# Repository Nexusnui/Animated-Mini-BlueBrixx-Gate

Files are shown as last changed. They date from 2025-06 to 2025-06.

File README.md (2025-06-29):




# Animated-Mini-BlueBrixx-Gate (Instructions are currently WIP)
Animated Mini BlueBrixx Gate:
Gif of BlueBrixx Stargate

# About this project
With this project you can add a screen to your Mini Stargates from BlueBrixx, that display an animation of the event horizon.

# Partlist:
You can find all parts required for building the screen in the [Partlist](PARTLIST.md).

# Printing:
Advice/Settings for printing the shell can be found [here](3D_PRINTING.md)

# Software:
There are two ways top get the firmware onto the device the easiest beeing by [flashing the precompiled firmware](FLASH_FIRMWARE.md)(Only Windows) or [compiling it with Arduino](COMPILE_FIRMWARE.md).

# Assembly:
After printing and flashing the firmware you can follow this [assembly guide](ASSEMBLY.md) to put everything together.

# Sources:
- The main code uses a modified version of the [Gif viewer example(GIFDEC)](https://github.com/moononournation/Arduino_GFX/tree/master/examples/ImgViewer/ImgViewerAnimatedGIF_GIFDEC) from the [Arduino GFX library](https://github.com/moononournation/Arduino_GFX).
- The animtation was created based the one provided by David Gian-Cursion in [this blogpost](https://www.gian-cursio.net/2025/02/mr-stargate-puddle/). The current version has a blue tint and an alternative with the original colors will be provided later.
- The arduino sketch also includes some driver files from the demo provided on the [waveshare wiki](https://www.waveshare.com/wiki/ESP32-S3-LCD-1.85#Resources). I am not sure under what license they are provided, if you know any better or are from waveshare inform me and I will update this project accordingly.

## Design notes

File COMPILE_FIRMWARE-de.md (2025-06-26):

Hier ist die Anleitung zum Kompilieren der Firmware mit Arduino.

# 1. Arduino IDE 2.0 installieren

Installieren Sie zunächst die Arduino IDE für Ihr Betriebssystem (Windows/Mac/Linux). Sie können sie von [der offiziellen Arduino-Website](https://www.arduino.cc/en/software/), dem Windows Store, Flathub und anderen Quellen herunterladen.

# 2. Unterstützung für ESP32-Boards hinzufügen

1. Gehen Sie zu File->Preferences
2. Fügen Sie unter Settings die URL des Boardmanagers von Espressif Systems in das Feld „Additional board managers URLs“ ein.
	`https://espressif.github.io/arduino-esp32/package_esp32_index.json`
3. Speichern Sie Ihre Einstellungen, indem Sie auf „ok“ klicken.
4. Suchen Sie im Boardmanager nach esp32 und installieren Sie "esp32 by Espressif Systems" (>= 3.0.2).
5. Warten Sie, bis die Installation abgeschlossen ist.

Das Waveshare Wiki bietet die gleiche Anleitung auf English mit Bildern hier:  
[https://www.waveshare.com/wiki/Arduino_Board_Managers_Tutorial]

# 3. Arduino GFX installieren

1. Öffnen Sie den Bibliotheksmanager.
2. Suchen Sie nach "GFX Library for Arduino" (von "Moon On Our Nation").
3. Installiere sie diese (Version 1.6.0).

# 4. Den Arduino-Sketch herunterladen und öffnen

Folge diesen Schritten:
1. [Downloade die aktuell Quellcode Zip Datei](https://github.com/Nexusnui/Animated-Mini-BlueBrixx-Gate/releases/latest/download/Animated-Mini-BlueBrixx-Gate.zip)
2. Entpacken Sie den Inhalt der ZIP-Datei.
3. Gehen Sie zu "Animated-Mini-BlueBrixx-Gate-main/Code/animated-gate".
4. Öffnen Sie "animated-gate.ino" mit der Arduino IDE (ein Doppelklick sollte genügen).

# 5. Bereiten Sie die SD-Karte vor

1. Formatieren Sie Ihre SD-Karte mit „Fat32“ (je nach Betriebssystem benötigen Sie eventuell zusätzliche Software)
2. Verschieben Sie die Datei „PuddleLoop.gif“ aus dem Datenordner (innerhalb des Sketch-Ordners) auf die SD-Karte
3. Stecken Sie die Karte in das Display.

# 6. Stellen Sie die richtigen Projektparameter ein

1. Verbinden Sie das Display mit Ihrem PC über ein USB-C-Kabel
2. In Arduino IDE gehen Sie zu Tool->Board->esp32 und wählen Sie "ESP32S3 Dev Module"
3. Nehmen sie unter Tools die folgenden Einstellungen vor:
   - 'Events Run On: "Core 0"'
   - 'Flash Mode: "QIO 120MHz"'
   - 'Flash Size: "16MB (128Mb)"'
   - 'Arduino Runs On: "Core 1"'
   - 'USB Firmware MSC On Boot: "Disabled"'
   - 'Partition Scheme: "16M Flash (3MB APP/9.9MB FATFS)"'
   - 'PSRAM: "OPI PSRAM"'
   
Das Waveshare Wiki hat in Bild für die Einstellungen unter Tools (es zeigt aber ein anderes Partitionsschema):
[https://www.waveshare.com/wiki/ESP32-S3-LCD-1.85#Arduino_project_parameter_setting]

# 7. Hochladen des Sketches

1. Klicken Sie auf die Schaltfläche Upload.
2. Warten Sie, bis die Skizze kompiliert und hochgeladen ist.
3. Sie sollten nun die PuddleLoop-Animation auf dem Bildschirm sehen.

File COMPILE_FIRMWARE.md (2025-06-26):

These are the instructions for compiling the firmware with Arduino.

# 1. Install Arduino IDE 2.0

First install Arduino IDE for your operating system(Windows/Mac/Linux). You can download it from [the official Arduino website](https://www.arduino.cc/en/software/), the Windows Store, Flathub and other sources.

# 2. Add support for ESP32 boards

1. Go to File->Preferences
2. Under settings paste Espressif Systems board manager url into the "Additional board managers URLs" field.
	`https://espressif.github.io/arduino-esp32/package_esp32_index.json`
3. Save your settings by clicking 'ok'
4. In the board manager search for esp32 and inatall 'esp32 by Espressif Systems' (>= 3.0.2)
5. Wait for the installation to finish

The Waveshare Wiki provides the same guide with images here:  
[https://www.waveshare.com/wiki/Arduino_Board_Managers_Tutorial]

# 3. Install Arduino GFX

1. Open the library manager
2. Search for 'GFX Library for Arduino' (by 'Moon On Our Nation')
3. Install it (version 1.6.0)

# 4. Get the Arduino Sketch and open it

Follow these steps:  
1. [Download the latest released source code zip file](https://github.com/Nexusnui/Animated-Mini-BlueBrixx-Gate/releases/latest/download/Animated-Mini-BlueBrixx-Gate.zip)
2. Extract the content of the ZIP File
3. Go to 'Animated-Mini-BlueBrixx-Gate-main/Code/animated-gate'
4. Open 'animated-gate.ino' with Arduino IDE (just double clicking should work)

# 5. Prepare the SD Card

1. Format your sd card to "Fat32"(depending on your operating system you may require additional software)
2. Move the file "PuddleLoop.gif" from the data folder(inside the Sketch folder) to the sd Card
3. Insert the card into the display

# 6. Set the correct project parameters

1. Connect the display with your pc through a usb-c cable
2. In Arduino IDE go to Tool->Board->esp32 and select "ESP32S3 Dev Module"
3. Under tools apply the following settings:
   - 'Events Run On: "Core 0"'
   - 'Flash Mode: "QIO 120MHz"'
   - 'Flash Size: "16MB (128Mb)"'
   - 'Arduino Runs On: "Core 1"'
   - 'USB Firmware MSC On Boot: "Disabled"'
   - 'Partition Scheme: "16M Flash (3MB APP/9.9MB FATFS)"'
   - 'PSRAM: "OPI PSRAM"'
   
The Waveshare Wiki has in Image for the settings under tools(it shows a different partition scheme):
[https://www.waveshare.com/wiki/ESP32-S3-LCD-1.85#Arduino_project_parameter_setting]

# 7. Upload the Sketch

1. Hit the upload button
2. Wait for the Sketch to compile and Upload
3. You should now see the PuddleLoop animation on the screen

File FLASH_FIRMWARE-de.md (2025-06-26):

Dies sind die Anweisungen zum Flashen der bereits kompilierten Firmware. (Die kompilierte Firmware ist noch nicht verfügbar)

# 1. Bereiten Sie die SD-Karte vor
1. Formatieren Sie Ihre SD-Karte mit „Fat32“ (je nach Betriebssystem benötigen Sie eventuell zusätzliche Software)
2. Verschieben Sie die Datei „PuddleLoop.gif“ aus dem Datenordner (innerhalb des Sketch-Ordners) auf die SD-Karte
3. Stecken Sie die Karte in das Display.

# 2. Flashen Sie die Firmware
1. [Lade Sie die aktuelle Firmware herunter](https://github.com/Nexusnui/Animated-Mini-BlueBrixx-Gate/releases/latest/download/Animated-Mini-BlueBrixx-Gate.bin)
2. Befolgen Sie die Anweisungen im [Waveshare Wiki](https://www.waveshare.com/wiki/Flash_Firmware_Flashing_and_Erasing), aber wählen Sie die Firmware, die Sie zuvor heruntergeladen haben.

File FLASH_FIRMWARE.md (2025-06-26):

These are the instructions for flashing the already compiled firmware.

# 1. Prepare the SD Card
1. Format your sd card to "Fat32"(depending on your operating system you may require additional software)
2. Move the file "PuddleLoop.gif" from the data folder(inside the Sketch folder) to the sd Card
3. Insert the card into the display

# 2. Flash the firmware
1. [Download the latest released firmaware](https://github.com/Nexusnui/Animated-Mini-BlueBrixx-Gate/releases/latest/download/Animated-Mini-BlueBrixx-Gate.bin)
2. Follow the instructions from the [Waveshare Wiki](https://www.waveshare.com/wiki/Flash_Firmware_Flashing_and_Erasing), but select the firmware you downloaded previously.

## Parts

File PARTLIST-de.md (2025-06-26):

Dies ist die Teileliste für dieses Projekt

| Teil | Anzahl | Anmerkungen |
| :---: | -----: | :--- |
| Waveshare-ESP32-S3-LCD-1.85 | 1x | Die Version ohne Touch wird benötigt, wegen dem kleineren Rahmen hat |
| M2-Schrauben | 3x | Getestet mit einer Länge von 4 mm, etwas länger sollte auch funktionieren  |
| Bedruckte Mini Stargate Fliesen | 4x | Aus einem BlueBrixx-Set, das sie enthält |
| Tile, Round 1 x 1 with Bar and Pin Holder(20482) | 2x | Kann bei Händlern für Einzelsteine gekauft werden |
| Spule PLA (wenn man es selbst druckt) | ca.11g | Das Filament "Schimmernde Nacht" von Recycling Fabrik funktioniert gut |
| USB-C Kabel auf C/A (mit Datentransfer) | 1x | Kann ein rechtwinkliges sein oder man verwendet einen zusätzlichen Adapter |

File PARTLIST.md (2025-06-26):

This the partlist for this project

| Part | Count  | Notes |
| :---: | -----: | :--- |
| Waveshare-ESP32-S3-LCD-1.85 | 1x | The version without touch is required since it has a smaller bezel |
| M2 Screws | 3x | Tested with a length of 4mm slightly longer should work too |
| Tiles from Mini Stargate | 4x | Can be sourced from an BlueBrixx set that includes them. |
| Tile, Round 1 x 1 with Bar and Pin Holder(20482) | 2x | Can be sourced from shops that sell bricks |
| Spool of PLA (if you print it yourself) | ca.11g | The Filament "Schimmernde Nacht" by Recycling Fabrik works well |
| USB-C Cablet to C/A(with data transfer) | 1x | Can be a right angled one or use an additional adapter |

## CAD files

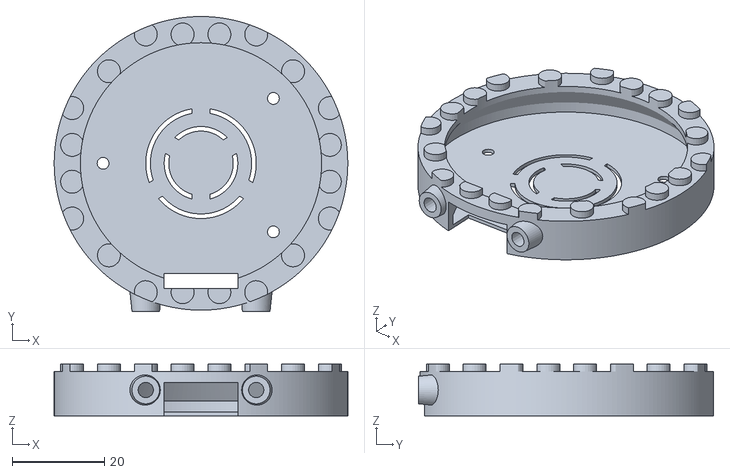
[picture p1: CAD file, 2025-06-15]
3D_Models/Screen_Shell.stl
63.8 x 64.1 x 11.2

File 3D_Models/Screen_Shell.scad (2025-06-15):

//Stud Tolerance added to the radius of a stud
st = 0.1; // .025

// include vent holes
include_vents = true;

/* [Curve Quality] */
// minimum angle for a fragment
$fa=2;
// minimum size of a fragment
$fs=0.6;

/* [Screen Offset Correction] */
//Correction of screen position on x axis.
screw_x_corr=0; // .025
//Correction of screen position on y axis.
screw_y_corr=0; // .025

module __Customizer_Limit__ () {}  // Hide following assignments from Customizer.

//Brick Variables names:
brick_b_u = 1.6;
brick_s_d = 3*brick_b_u;
brick_h = 6  * brick_b_u;
brick_p_h = 2 * brick_b_u;
brick_g_u = 5 * brick_b_u;

//Brick Variables as functions forexternal use:
function brick_base_unit(size=1) = brick_b_u*size;
function brick_stud_diameter(size=1) = brick_s_d*size;
function brick_heigth(size=1) = brick_h*size;
function brick_plate_heigth(size=1) = brick_p_h*size;
function brick_grid_unit(studs=1) = brick_g_u*studs;


gate_outer_d = 63.8;
screen_h = 8.7+0.1;
housing_h = brick_heigth();
housing_inner_d =52.4;
housing_bottom = housing_h-screen_h;

screw_dist = 23.93;
screw_x1 = -21.27;
screw_x2 = 15.73;
screw_y2 = 14.10;
screw_y3 = -14.90;
screw_shaft_d = 2+0.6;
echo(housing_inner_d);



module translate_brick(pos){
    b_g_x = pos[0] * brick_g_u;
    b_g_y = pos[1] * brick_g_u;
    if (is_num(pos[2])){
        b_g_z = pos[2] * brick_p_h;
        translate([ b_g_x, b_g_y, b_g_z])children();
    }else{
        translate([ b_g_x, b_g_y, 0])children();
    }
}

module stud(center=false,stud_tolerance=brick_st){
    if(center){
        cylinder(d=brick_s_d+stud_tolerance*2,h = brick_b_u);      
    }else{
        translate_brick([0.5,0.5,0])cylinder(d=brick_s_d+stud_tolerance*2,h = brick_b_u);
    }
}

module housing(){
difference(){
union(){
cylinder(d=gate_outer_d,h=housing_h);

translate([0,-0.2,0])translate_brick([1.5,-4,1.75])rotate([-90,0,0])cylinder(h=brick_heigth(),d2=brick_grid_unit(),d1=brick_stud_diameter(1.25));
translate([0,-0.2,0])translate_brick([-1.5,-4,1.75])rotate([-90,0,0])cylinder(h=brick_heigth(),d2=brick_grid_unit(),d1=brick_stud_diameter(1.25));
}
translate([0,-0.2,0])translate_brick([1.5,-4,1.75])rotate([-90,0,0])cylinder(h=brick_heigth()+0.4,d=brick_base_unit(2)+0.15);
translate([0,-0.2,0])translate_brick([-1.5,-4,1.75])rotate([-90,0,0])cylinder(h=brick_heigth()+0.4,d=brick_base_unit(2)+0.15);

translate([0,0,housing_bottom])cylinder(d=housing_inner_d,h=screen_h+0.01);

translate([screw_x_corr,screw_y_corr,0])screw_holes();


translate([-brick_grid_unit(),-gate_outer_d/2,0])cube([brick_grid_unit(2),brick_grid_unit(),brick_plate_heigth(2)+housing_bottom]);

translate([-brick_grid_unit(),-housing_inner_d/2-1,0])cube([brick_grid_unit(2),3,housing_h]);


translate([0,0,housing_bottom+brick_plate_heigth(0.75)])cylinder(d1=gate_outer_d-3,h=5,d2=housing_inner_d);
translate([0,0,housing_bottom])cylinder(d=gate_outer_d-3,h=brick_plate_heigth(0.75));

if (include_vents){
difference(){
cylinder(d=brick_grid_unit(3),h=housing_bottom);
cylinder(d=brick_grid_unit(2.75),h=housing_bottom);
rotate([0,0,120+90])translate_brick([0,-0.25,0])cube([brick_grid_unit(2.5),brick_grid_unit(0.5),housing_bottom]);
rotate([0,0,-120+90])translate_brick([0,-0.25,0])cube([brick_grid_unit(2.5),brick_grid_unit(0.5),housing_bottom]);
rotate([0,0,90])translate_brick([0,-0.25,0])cube([brick_grid_unit(2.5),brick_grid_unit(0.5),housing_bottom]);
}

difference(){
cylinder(d=brick_grid_unit(2),h=housing_bottom);
cylinder(d=brick_grid_unit(1.75),h=housing_bottom);
rotate([0,0,120-90])translate_brick([0,-0.25,0])cube([brick_grid_unit(2.5),brick_grid_unit(0.5),housing_bottom]);
rotate([0,0,-120-90])translate_brick([0,-0.25,0])cube([brick_grid_unit(2.5),brick_grid_unit(0.5),housing_bottom]);
rotate([0,0,-90])translate_brick([0,-0.25,0])cube([brick_grid_unit(2.5),brick_grid_unit(0.5),housing_bottom]);
}
}

}


cut_studs();

}



module cut_studs(){
difference(){
union(){
translate_brick([3,0,3])stud(false,st);
translate_brick([-4,0,3])stud(false,st);

translate_brick([3,-1,3])stud(false,st);
translate_brick([-4,-1,3])stud(false,st);

translate_brick([0,3,3])stud(false,st);
translate_brick([-1,3,3])stud(false,st);

translate_brick([0,-4,3])stud(false,st);
translate_brick([-1,-4,3])stud(false,st);

translate_brick([2,2,3])stud(false,st);
translate_brick([-3,2,3])stud(false,st);

translate_brick([2,-3,3])stud(false,st);
translate_brick([-3,-3,3])stud(false,st);

translate_brick([3,-2,3])stud(false,st);
translate_brick([-4,-2,3])stud(false,st);

translate_brick([3,1,3])stud(false,st);
translate_brick([-4,1,3])stud(false,st);

translate_brick([1,3,3])stud(false,st)
translate_brick([-2,3,3])stud(false,st);

translate_brick([1,-4,3])stud(false,st)
translate_brick([-2,-4,3])stud(false,st);
translate_brick([-2,-4,3])stud(false,st);
translate_brick([-2,3,3])stud(false,st);
}

translate_brick([0,0,3])cylinder(d=housing_inner_d,h=housing_h+0.01);

translate_brick([0,0,3])difference(){
cylinder(d=gate_outer_d+brick_stud_diameter(),h=housing_h);
cylinder(d=gate_outer_d,h=housing_h);
}
translate([-brick_grid_unit(),-housing_inner_d/2-1,brick_plate_heigth(3)])cube([brick_grid_unit(2),3,housing_h]);


}

}

module screw_holes(){
    translate([screw_x1,0,0])cylinder(d=screw_shaft_d,h=housing_bottom+0.01);
translate([screw_x2,screw_y2,0])cylinder(d=screw_shaft_d,h=housing_bottom+0.01);
translate([screw_x2,screw_y3,0])cylinder(d=screw_shaft_d,h=housing_bottom+0.01);
}

housing();

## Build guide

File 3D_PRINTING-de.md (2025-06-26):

Hier sind einige Hinweise zum Drucken des Gehäuses.

# 1. Holen Sie sich das Modell
[Diese stl-Datei](3D_Models/Screen_Shell.stl) des Gehäuses verwendet die Standardeinstellungen.
Wenn du das Modell anpassen möchtest, kannst du das mit dem Customizer auf [der Thingiverse-Seite](https://www.thingiverse.com/thing:7061084) tun (derzeit kaputt).
Die andere Möglichkeit ist, [Screen_Shell.scad](3D_Models/Screen_Shell.scad) in [OpenScad](https://openscad.org/) zu öffnen und dort den Customizer zu verwenden.

# 2. Das Filament
Ich habe das Pla-Filement ["Schimmernde Nacht"](https://www.recyclingfabrik.com/products/schimmernde-nacht) von Recycling Fabrik verwendet, da es der von BlueBrixx verwendeten Gunmetal-Farbe sehr ähnlich ist.

# 3. Druckeinstellungen
Ich habe die folgenden Einstellungen verwendet, um mein Modell zu drucken:
- Schichthöhe: 0.2mm
- Füllung: 15%
- Stützen: Organisch
Optional:
- Decken-/Bodenfüllmuster: Konzentrisch

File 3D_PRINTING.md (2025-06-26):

Here is some advice on printing the shell.

# 1. Get the model
[This stl file](3D_Models/Screen_Shell.stl) of the shell uses the default settings.
If you want to tweak the model you can do that with the customizer on [the Thingiverse page](https://www.thingiverse.com/thing:7061084)(currently broken).
The other option is to open [Screen_Shell.scad](3D_Models/Screen_Shell.scad) in [OpenScad](https://openscad.org/) and use the customiser there.

# 2. The Filament
I used the pla filement ["Schimmernde Nacht"](https://www.recyclingfabrik.com/products/schimmernde-nacht) from Recycling Fabrik since it is close to the gunmetal color used by BlueBrixx.

# 3. Print settings
I used the following settings to print my model:
- Layer Height: 0.2mm
- Infill: 15%
- Support: Organic
Optional:
- Top/Botton-Fill_Pattern: Concentric

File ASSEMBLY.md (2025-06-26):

This is the guide for assembling the gate.

# 1. Insert the SD Card
Insert the sd card you prepared in the [Flashing](FLASH_FIRMWARE.md) or [Compiling](COMPILE_FIRMWARE.md) instructions.

# 2. Insert the screen into the shell
Be carefull with the sd card. 
If you use the speaker or pin-breakout(they are currently not used in this project) pull them through the gap on the side of the shell and plug them into the screen.
Insert the screen into the shell from the top, the usb c port should point towards the gap on the side.

# 3. Screw in the screen
Flip the screen and use 3x m2 screws to mount the screen the shell.
You can now remove the foil on the screen, if it is still on there.

# 4. Add bricks
Add the 4x stargate tiles to the front and 2x round tiles with bar(20482) to the holes next to the qap on the side.

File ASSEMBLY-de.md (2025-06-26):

Dies ist die Anleitung für den Zusammenbau des Gates.

# 1. Legen Sie die SD-Karte ein
Legen Sie die SD-Karte ein, die Sie in der Anleitung [Flashen](FLASH_FIRMWARE-de.md) oder [Kompileren](COMPILE_FIRMWARE-de.md) vorbereitet haben.

# 2. Legen Sie den Bildschirm in das Gehäuse ein
Seien Sie vorsichtig mit der SD-Karte. 
Wenn Sie den Lautsprecher oder den Pin-Breakout verwenden (werden in diesem Projekt derzeit nicht verwendet), ziehen Sie sie durch die Lücke an der Seite des Gehäuses und stecken Sie sie in den Bildschirm.
Setzen Sie den Bildschirm von oben in das Gehäuse ein, der USB-C-Anschluss sollte in Richtung der seitlichen Lücke zeigen.

# 3. Schrauben Sie den Bildschirm ein
Drehen Sie den Bildschirm um und verwenden Sie 3x M2 Schrauben, um den Bildschirm am Gehäuse zu befestigen.
Sie können nun die Folie auf dem Bildschirm entfernen, falls sie noch darauf ist.

# 4. Steine hinzufügen
Füge die 4 Stargate-Fliesen an der Vorderseite und 2 runde Fliesen mit Bar (20482) in den Löchern neben dem Lücke an der Seite hinzu.

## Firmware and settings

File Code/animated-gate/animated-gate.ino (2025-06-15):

/*******************************************************************************
 * Animated GIF Image Viewer
 * This is a Animated GIF of Stargate Event Horizon example based on Example from Arduino GFX
 * Image Source: Todo
 * cropped: resized: 360x360
 * optimized with ezgif.com
 *
 * GIFDEC original source: https://github.com/BasementCat/arduino-tft-gif
 ******************************************************************************/
/* Wio Terminal */
#define GIF_FILENAME "/PuddleLoop.gif"

/*******************************************************************************
 * Start of Arduino_GFX setting
 ******************************************************************************/

#include <Arduino_GFX_Library.h>

#define GFX_BL 5 //backlight pin

/* data bus class */
Arduino_DataBus *bus = new Arduino_ESP32QSPI(21 /* cs */, 40 /* sck */, 46 /* d0 */, 45 /* d1 */, 42 /* d2 */, 41 /* d3 */, false);

/* display class */
Arduino_GFX *gfx = new Arduino_ST77916(bus /*bus*/, -1 /*rst*/, 0 /*rotation*/, true /*ips*/, 360 /*width*/, 360 /*height*/);

/*******************************************************************************
 * End of Arduino_GFX setting
 ******************************************************************************/

/* Wio Terminal */
#include "SD_Card.h"

#include "GifClass.h"
static GifClass gifClass;

void setup()
{

//Todo: Check if this is required
#ifdef DEV_DEVICE_INIT
  DEV_DEVICE_INIT();
#endif

  //Todo: Define Dev Mode Var
  //Serial.begin(115200);
  // Serial.setDebugOutput(true);
  // while(!Serial);
  //Serial.println("Arduino_GFX Animated GIF Image Viewer example");

  // Init Display
  if (!gfx->begin())
  {
    //Serial.println("gfx->begin() failed!");
  }
  gfx->fillScreen(RGB565_BLACK);

#ifdef GFX_BL
  pinMode(GFX_BL, OUTPUT);
  digitalWrite(GFX_BL, HIGH);
#endif

/* Wio Terminal */
SD_Init();
}

void loop()
{
/* Wio Terminal */
File gifFile = SD_MMC.open(GIF_FILENAME);

  if (!gifFile || gifFile.isDirectory())
  {
    //Serial.println(F("ERROR: open gifFile Failed!"));
    gfx->println(F("ERROR: open gifFile Failed!"));
  }
  else
  {
    // read GIF file header
    gd_GIF *gif = gifClass.gd_open_gif(&gifFile);
    if (!gif)
    {
      //Serial.println(F("gd_open_gif() failed!"));
    }
    else
    {
      uint8_t *buf = (uint8_t *)malloc(gif->width * gif->height);
      if (!buf)
      {
        //Serial.println(F("buf malloc failed!"));
      }
      else
      {
        int16_t x = (gfx->width() - gif->width) / 2;
        int16_t y = (gfx->height() - gif->height) / 2;

        //Serial.println(F("GIF video start"));
        int32_t start_ms = millis(), t_delay = 0, delay_until;
        int32_t res = 1;
        int32_t duration = 0, remain = 0;
        while (res > 0)
        {
          t_delay = gif->gce.delay * 10;
          res = gifClass.gd_get_frame(gif, buf);
          if (res < 0)
          {
            //Serial.println(F("ERROR: gd_get_frame() failed!"));
            break;
          }
          else if (res > 0)
          {
            gfx->drawIndexedBitmap(x, y, buf, gif->palette->colors, gif->width, gif->height);

            duration += t_delay;
            delay_until = start_ms + duration;
            while (millis() < delay_until)
            {
              delay(1);
              remain++;
            }
          }
        }
        /*Serial.println(F("GIF video end"));
        Serial.print(F("Actual duration: "));
        Serial.print(millis() - start_ms);
        Serial.print(F(", expected duration: "));
        Serial.print(duration);
        Serial.print(F(", remain: "));
        Serial.print(remain);
        Serial.print(F(" ("));
        Serial.print(100.0 * remain / duration);
        Serial.println(F("%)"));
        */

        gifClass.gd_close_gif(gif);
        free(buf);
      }
    }
  }
}

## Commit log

2025-06-15 Added Project
    Added the initial state of the project files.
    [Screen_Shell.scad, Screen_Shell.stl]
2025-06-15 Create arduino-gfx-license.txt
    added license from arduino gfx
2025-06-26 Added 3D_PRINTING.md
    Added 3D_PRINTING.md with some advice for 3D printing
2025-06-26 Added ASSEMBLY.md
    Added ASSEMBLY.md with assembly instructions.
2025-06-26 Printing and Assembly in Readme
    Printing and Assembly were linked in the readme.
2025-06-26 Corrected Assembly.md
